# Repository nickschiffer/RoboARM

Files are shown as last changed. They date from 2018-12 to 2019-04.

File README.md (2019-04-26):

# RoboARM
## [Link to Hackster.io Post](https://www.hackster.io/154072/roboarm-texas-instruments-powered-3d-printed-robotic-arm-043960 "Hackster.io Post")
RoboARM utilizes a TM4C123GH6PM microcontroller to interpret inputs from an old analog joystick to control the servos that drive the arm; while at the same time making sure that the arm abides by the set movement bounds of the hardware. The microcontroller implements the added functionality of being able to record, store, and ultimately repeat routines that the operator performs.

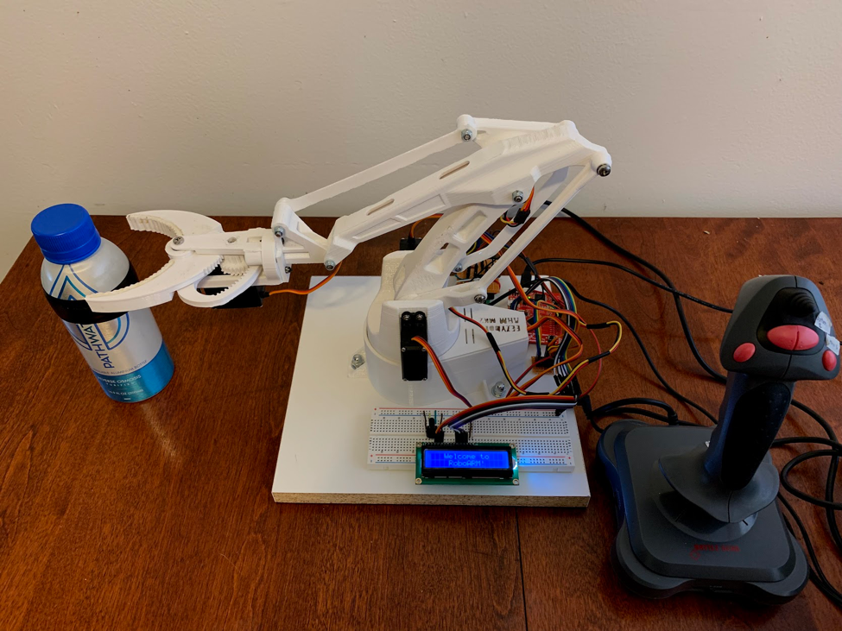
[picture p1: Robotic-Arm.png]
RoboARM


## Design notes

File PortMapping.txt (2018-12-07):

Pin Mappings:
    Joystick:
      (Port) : (Function) : (Signal)
       PB5   :    X1      : Analog
       PE4   :    Y1      : Analog
       PB1   :    B2      : Digital
       PB4   :    B3      : Digital
       PB3   :    B1      : Digital
       PB2   :    B4      : Digital
    Arm:
      (Port)   : (Function)   (Color)  : (Signal)
        PE0    : Up/Down      (Black)  :   PWM
        PE5    : Forward/Back (Green)  :   PWM
        PC5    : Claw	      (Yellow) :   PWM
        PC4    : Rotation     (Blue)   :   PWM

    Movement:
      Button 1: Close Claw
      Button 2: Up
      Button 3: Down
      Button 4: Open Claw

      x-axis: Rotation
      y-axis: Foward/Back

    Deadzone:
      x-avg = 1900 +/- 600
      y-avg = 1832 +/- 500

 The circuit for LCD:
 * LCD RS pin to digital pin 28 (PE2)
 * LCD Enable pin to digital pin 27  (PE1)
 * LCD D4 pin to digital pin 23 (PD0)
 * LCD D5 pin to digital pin 24 (PD1)
 * LCD D6 pin to digital pin 25 (PD2)
 * LCD D7 pin to digital pin 26 (PD3)
 * LCD R/W pin to ground
 * 10K resistor:
 * ends to +5V and ground
 * wiper to LCD VO pin (pin 3)

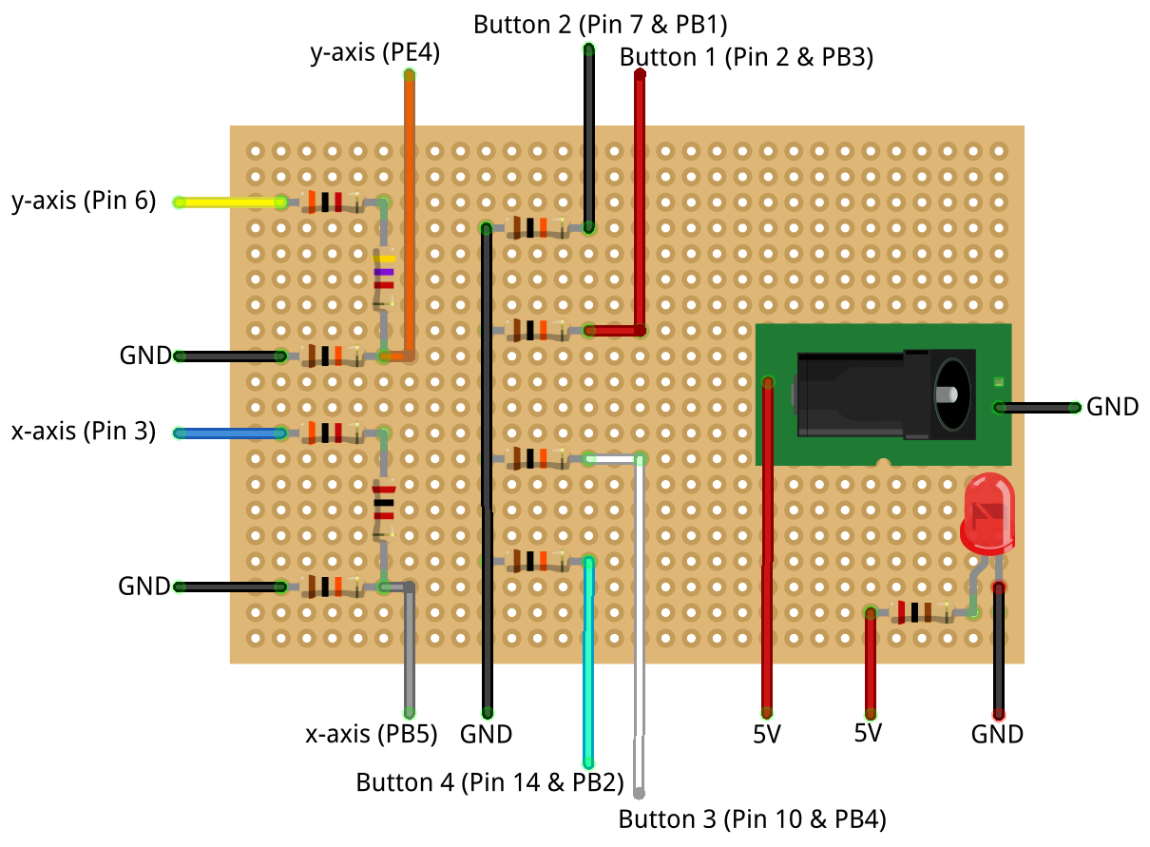
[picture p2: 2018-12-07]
Schematics/Circuit (VGA Connector).png

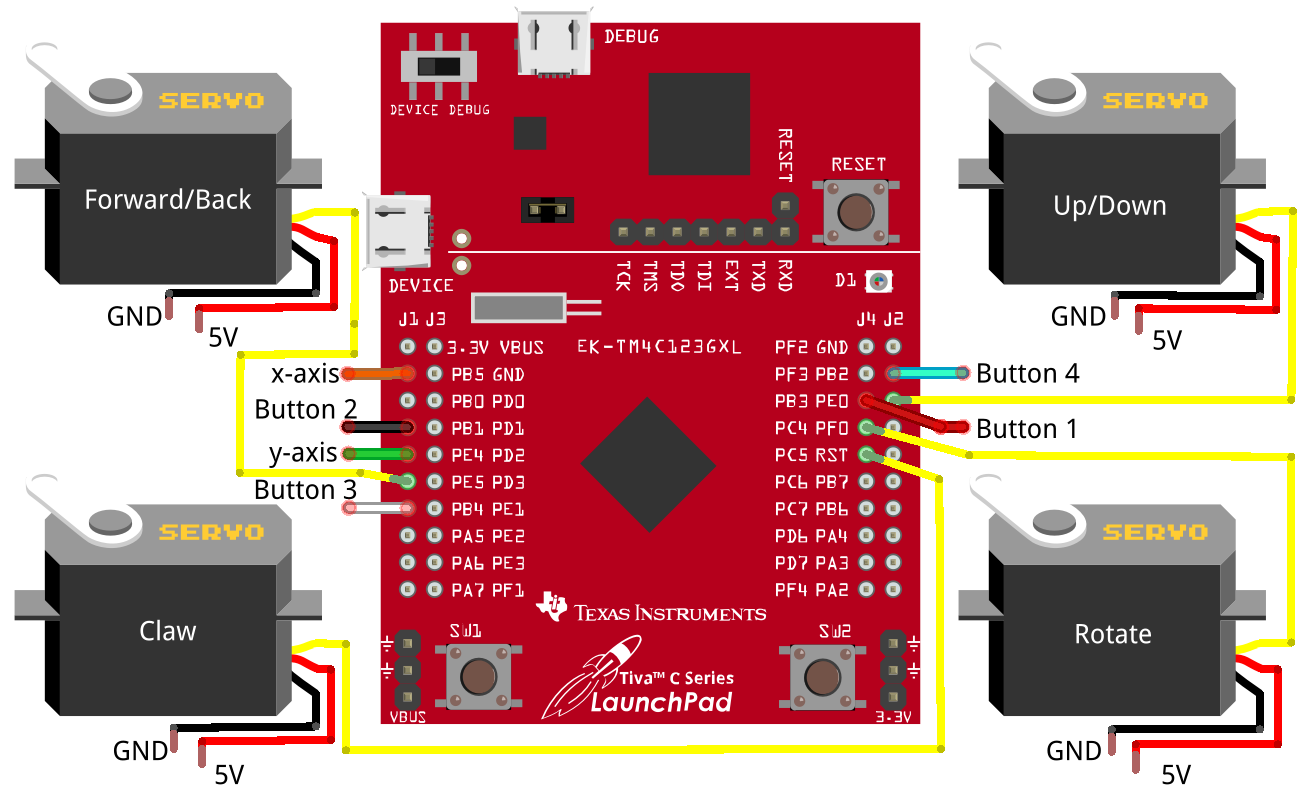
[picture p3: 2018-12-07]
Schematics/Tiva _ Servos.png

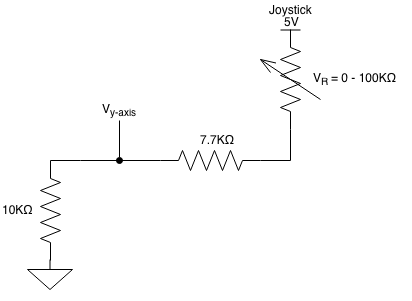
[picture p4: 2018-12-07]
Schematics/Voltage Divider (y-axis).png

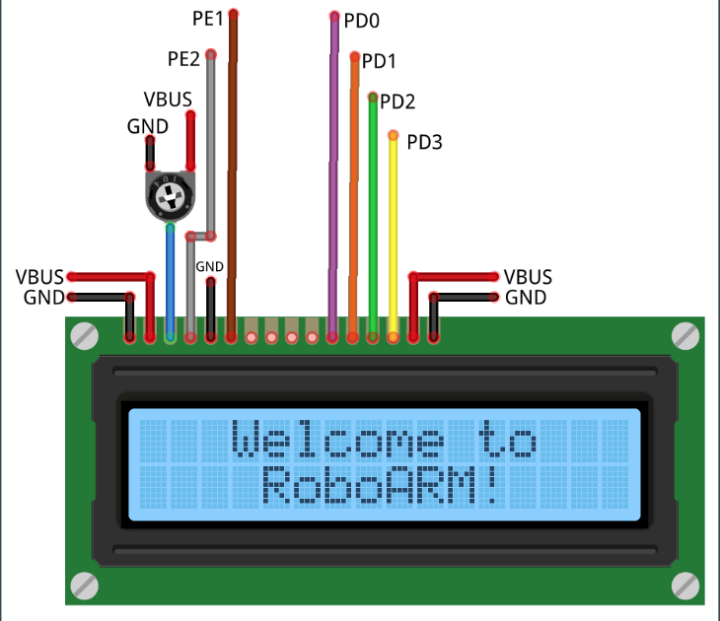
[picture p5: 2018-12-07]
Schematics/Screen Shot 2018-12-03 at 6.39.09 PM.png

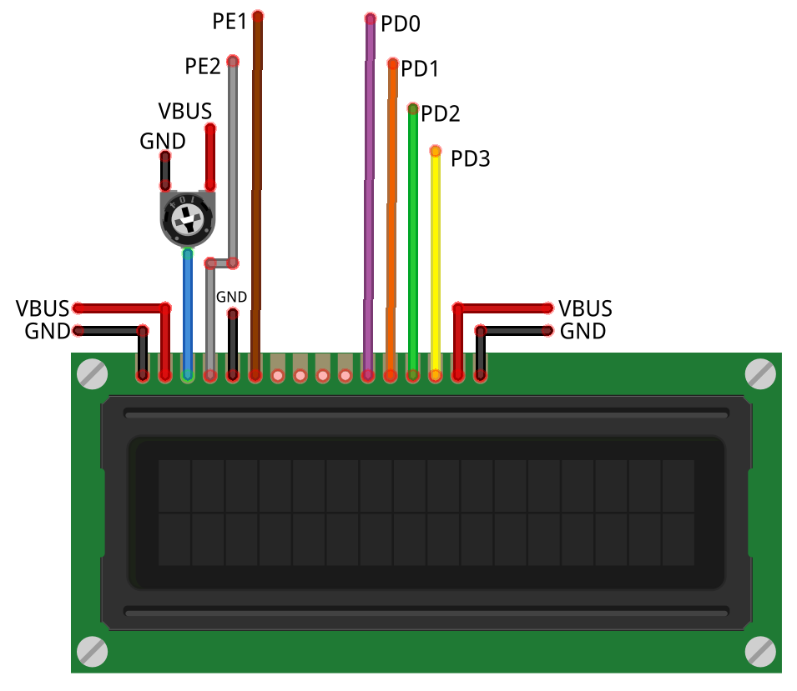
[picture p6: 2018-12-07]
Schematics/LCD Schematic.png

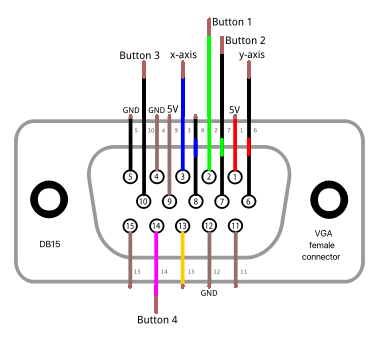
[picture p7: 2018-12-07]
Schematics/DB15 Connector Pins.png

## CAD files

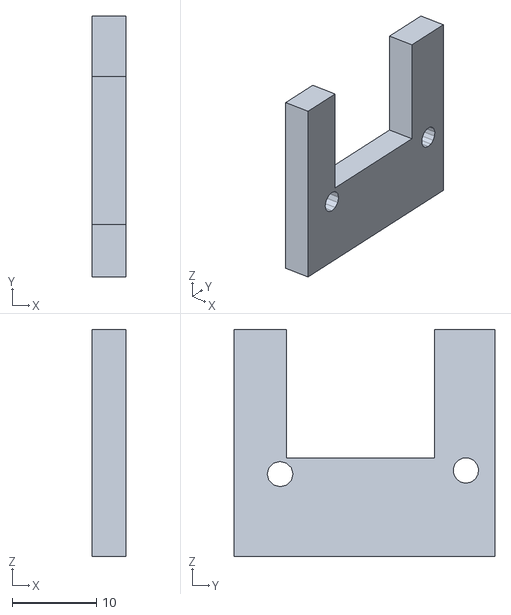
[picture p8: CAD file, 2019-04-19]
Claw-Adapter.stl
4.00 x 31.0 x 27.0

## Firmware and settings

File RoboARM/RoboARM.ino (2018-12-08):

/*
  RoboARM driver code:
  Pin Mappings:
    Joystick:
      (Port) : (Function) : (Signal)
       PB5   :    X1      : Analog
       PE4   :    Y1      : Analog
       PB1   :    B2      : Digital
       PB4   :    B3      : Digital
       PB3   :    B1      : Digital
       PB2   :    B4      : Digital
    Arm:
      (Port)   : (Function)   (Color)  : (Signal)
        PE0    : Up/Down      (Black)  :   PWM
        PE5    : Forward/Back (Green)  :   PWM
        PC5    : Claw         (Yellow) :   PWM
        PC4    : Rotation     (Blue)   :   PWM

    Movement:
      Button 1: Close Claw
      Button 2: Up
      Button 3: Down
      Button 4: Open Claw

      x-axis: Rotation
      y-axis: Foward/Back

    Deadzone:
      x-avg = 1900 +/- 600
      y-avg = 1832 +/- 500

 The circuit for LCD:
 * LCD RS pin to digital pin 28 (PE2)
 * LCD Enable pin to digital pin 27  (PE1)
 * LCD D4 pin to digital pin 23 (PD0)
 * LCD D5 pin to digital pin 24 (PD1)
 * LCD D6 pin to digital pin 25 (PD2)
 * LCD D7 pin to digital pin 26 (PD3)
 * LCD R/W pin to ground
 * 10K resistor:
 * ends to +5V and ground
 * wiper to LCD VO pin (pin 3)
 
 */
#include <stdio.h>
#include <Servo.h>
#include <LiquidCrystal.h> //https://github.com/energia/Energia/tree/master/libraries/LiquidCrystal


// #define DEBUG /* uncomment for Serial Debugging Output (causes severe lag with actual movements...Prints are expensive) */

//Servo Bounds
#define CLAW_OPEN_MAX 1
#define CLAW_CLOSED_MAX 150
#define CLAW_MOVEMENT_SPEED 5

#define ROTATE_LEFT_MAX 0
#define ROTATE_RIGHT_MAX 179
#define ROTATION_SPEED 2


#define UP_MAX 120
#define DOWN_MAX 74
#define UPDOWN_MOVEMENT_SPEED 2

#define DOWN_MAX_BACK 74
#define DOWN_MAX_FORWARD 0
int   downmax_height = 0;
int   downmax_width  = 0;
float downmax_slope  = 0;

#define FORWARD_MAX 179
#define BACK_MAX 89
#define FORWARD_BACK_SPEED 1
#define SENSITIVE_OFFSET 20

//Joystick Calibration
#define X_START 1900 //X Middle Point
#define Y_START 1832 //Y Middle Point
#define X_RANGE 600  //X Deadzone Threshold
#define Y_RANGE 500  //Y Deadzone Threshold

//recording
//#define RECORD_LENGTH (BUFSIZ + 500)
//#define RECORD_LENGTH (3*BUFSIZ + 500)
#define RECORD_LENGTH (6*BUFSIZ + 600)
int record_length =  RECORD_LENGTH;
//int record[RECORD_LENGTH][4];
//unsigned short int record[RECORD_LENGTH][4];
unsigned char record[RECORD_LENGTH][4];
int count = 0; //current recording position
bool recording = false;
bool playing   = false;
int cursor = 0;//current playback position

int progress_cursor = 0; // used for progress bar for recording and playback

//Inputs (used to store input values)
int x_val = 0;
int y_val = 0;

int B1_val = 0;
int B2_val = 0;
int B3_val = 0;
int B4_val = 0;


/* Analog */
int X1 = PB_5;
int Y1 = PE_4;
/* Digital */
int B2_pin = PB_1;
int B3_pin = PB_4;
int B1_pin = PB_3;
int B4_pin = PB_2; 

/* Servos */
int UpDown_pin      = PE_0;
int ForwardBack_pin = PE_5;
int Claw_pin        = PC_5;
int Rotate_pin      = PC_4;

/* Positional Variables */
int ClawPosition        = 0;
int RotationPosition    = 0;
int UpDownPosition      = 0;
int ForwardBackPosition = 0;

char str[200];

int current_down_max = 0;
bool adjusting_back  = false;

//Set up Servos
Servo UpDown;
Servo ForwardBack;
Servo Claw;
Servo Rotate;

// initialize the LCD library with the numbers of the interface pins (see mapping at top of file)
LiquidCrystal lcd(28, 27, 23, 24, 25, 26);

void moveClaw(char OpenOrClose){
  
  switch (OpenOrClose){
    case 'o' :
        if (ClawPosition > CLAW_OPEN_MAX + CLAW_MOVEMENT_SPEED){
            ClawPosition -= CLAW_MOVEMENT_SPEED;
            Claw.write(ClawPosition);
            #ifdef DEBUG
            sprintf(str, "Opening Claw. Claw Position: %d\n", ClawPosition);
            Serial.print(str);
            #endif
            
        }
        break;
    case 'c' :
        if (ClawPosition < CLAW_CLOSED_MAX - CLAW_MOVEMENT_SPEED){
            ClawPosition += CLAW_MOVEMENT_SPEED;
            Claw.write(ClawPosition);
            #ifdef DEBUG
            sprintf(str, "Closing Claw. Claw Position: %d\n", ClawPosition);
            Serial.print(str);
            #endif
        }
        break;
    case 'i':
        int default_val;
        default_val = (CLAW_CLOSED_MAX - CLAW_OPEN_MAX)/2;
        ClawPosition = default_val;
        Claw.write(default_val);
        #ifdef DEBUG
        sprintf(str, "Initializing CLaw. Claw Position: %d\n", ClawPosition);
        Serial.print(str);
        #endif
        break;
    default:
        break;
  }
}

void moveUpDown(char UpOrDown){
  
  switch (UpOrDown){
    case 'u' : //move up
        if (UpDownPosition + UPDOWN_MOVEMENT_SPEED < UP_MAX ){
            UpDownPosition += UPDOWN_MOVEMENT_SPEED;
            UpDown.write(UpDownPosition);
            #ifdef DEBUG
            sprintf(str, "Moving Up. UpDown Position: %d\n", UpDownPosition);
            Serial.print(str);
            #endif
            
        }
        break;
    case 'd' : //move down
            if (!adjusting_back){
              calcDownMax();
            }
        if (UpDownPosition - UPDOWN_MOVEMENT_SPEED > current_down_max){
            UpDownPosition -= UPDOWN_MOVEMENT_SPEED;
            UpDown.write(UpDownPosition);
            #ifdef DEBUG
            sprintf(str, "Moving Down. UpDown Position: %d, Current DownMax: %d\n", UpDownPosition, current_down_max);
            Serial.print(str);
            #endif
        }
        break;
    case 'i': //initialize
        int default_val;
        //default_val = abs(UP_MAX - DOWN_MAX)/2;
        default_val = 100;
        UpDown.write(default_val);
        UpDownPosition = default_val;
        #ifdef DEBUG
        sprintf(str, "Initializing UpDown. UpDown Position: %d\n", UpDownPosition);
        Serial.print(str);
        #endif
        break;
    default:
        break;
  }
}

void moveArmRotate(){
    //Rotate
    if (x_val > X_START + X_RANGE){ //Move if input value is outside of middle deadzone
      //Rotate Left
      if (ForwardBackPosition >= (FORWARD_MAX - SENSITIVE_OFFSET)){ //If close to the max front position, move more slowly
        if (RotationPosition - (ROTATION_SPEED - 1) >= ROTATE_LEFT_MAX){
          RotationPosition -= (ROTATION_SPEED - 1);
          Serial.println("Sensitive Left");
          Rotate.write(RotationPosition);
          #ifdef DEBUG
          sprintf(str, "Rotating Left. Rotation Position: %d\n", RotationPosition);
          Serial.print(str);
          #endif
        }
      }
      
      else if (RotationPosition - ROTATION_SPEED >= ROTATE_LEFT_MAX){ //check to see if movement will go out of bounds
        RotationPosition -= ROTATION_SPEED;
        Rotate.write(RotationPosition);
        #ifdef DEBUG
        sprintf(str, "Rotating Left. Rotation Position: %d\n", RotationPosition);
        Serial.print(str);
        #endif
      }
    }
    if (x_val < X_START - X_RANGE){ //Move if input value is outside of middle deadzone
      //Rotate Right
      if (ForwardBackPosition >= (FORWARD_MAX - SENSITIVE_OFFSET)){ //If close to the max front position, move more slowly
        if (RotationPosition + (ROTATION_SPEED - 1) <= ROTATE_RIGHT_MAX){ //check to see if movement will go out of bounds
          RotationPosition += (ROTATION_SPEED - 1);
          Serial.println("Sensitive Right");
          Rotate.write(RotationPosition);
          #ifdef DEBUG
          sprintf(str, "Rotating Right. Rotation Position: %d\n", RotationPosition);
          Serial.print(str);
          #endif
        }
      }
      else if (RotationPosition + ROTATION_SPEED <= ROTATE_RIGHT_MAX){ //check to see if movement will go out of bounds
        RotationPosition += ROTATION_SPEED;
        Rotate.write(RotationPosition);
        #ifdef DEBUG
        sprintf(str, "Rotating Right. Rotation Position: %d\n", RotationPosition);
        Serial.print(str);
        #endif
      }
    }
}

void moveArmForwardBack(){
  //Forward or Back
    if (y_val > Y_START + Y_RANGE){ //Move if input value is outside of middle deadzone
      //Move Forward
      if (ForwardBackPosition + FORWARD_BACK_SPEED <= FORWARD_MAX){ //check to see if movement will go out of bounds
        ForwardBackPosition += FORWARD_BACK_SPEED;
        ForwardBack.write(ForwardBackPosition);
        #ifdef DEBUG
        sprintf(str, "Moving Forward. ForwardBack Position: %d\n", ForwardBackPosition);
        Serial.print(str);
        #endif
      }
    }
    if (y_val < Y_START - Y_RANGE){ //Move if input value is outside of middle deadzone
      //Move Back
      if (ForwardBackPosition - FORWARD_BACK_SPEED >= BACK_MAX){ //check to see if movement will go out of bounds
        
        ForwardBackPosition -= FORWARD_BACK_SPEED;
        ForwardBack.write(ForwardBackPosition);
        #ifdef DEBUG
        sprintf(str, "Moving Back. ForwardBack Position: %d\n", ForwardBackPosition);
        Serial.print(str);
        #endif
        calcDownMax();
        /* If the arm is moved back and is lower than the lowest allowed position for that ForwardBackPosition, we need to move the arm up.*/
        if (UpDownPosition < current_down_max){
          #ifdef DEBUG
          Serial.println("adjusting\n");
          #endif
          adjusting_back = true;
          moveUpDown('u');
          adjusting_back = false;
        }
      }
    }
  
}

/* Used to calculate the lowest point the arm can go depending on its current ForwardBackPosition (Think Triangle, y=mx+b) */
void calcDownMax(){
  current_down_max = (int)((float)downmax_slope*(float)abs(FORWARD_MAX - ForwardBackPosition));
  #ifdef DEBUG
  sprintf(str, "height: %d, width: %d, slope: %g, currentdownmax: %d\n", downmax_height, downmax_width, downmax_slope, current_down_max);
  Serial.print(str);
  #endif
  
}

/* Prints the Welcome Message when the bot is powered on or reset */
void printWelcome(){
  // set up the LCD's number of columns and rows: 
  lcd.begin(16, 2);
  // Print a message to the LCD.
  lcd.print("   Welcome to");
  delay(2000);
  lcd.setCursor(0, 1);
  lcd.print("    RoboARM!");
  delay(2000);
  lcd.setCursor(0,0);
  lcd.print("                ");
  lcd.setCursor(0,1);
  lcd.print("   Welcome to");
  delay(750);
  lcd.clear();
  lcd.setCursor(0,0);
  lcd.print("Initializing");
  int lcd_cursor = 12;
  for (int i = 0; i < 3; i++){
    for (int j = 0; j < 3; j++){
      lcd.setCursor(lcd_cursor++, 0);
      lcd.print(".");
      delay(600);
    }
    lcd.setCursor(12,0);
    lcd.print("   ");
    lcd_cursor = 12;
    delay(500);
  }
  byte block[8] = {
    0b00000,
    0b11111,
    0b11111,
    0b11111,
    0b11111,
    0b11111,
    0b11111,
    0b00000  
  };
  lcd.createChar(0, block);
  byte play[8] = {
    0b01000,
    0b01100,
    0b01110,
    0b01111,
    0b01110,
    0b01100,
    0b01000,
    0b00000
  };
  lcd.createChar(1, play);
  byte rec[8] = {
    0b00000,
    0b01110,
    0b11111,
    0b11111,
    0b11111,
    0b01110,
    0b00000,
    0b00000
  };
  lcd.createChar(2, rec);
}

void setup() {
  
  
  
  Serial.begin(9600);
  Serial.print("Starting\n");
  printWelcome();
  lcd.setCursor(0,0);
  lcd.print("Mode: Manual");
  //Setup digital inputs
  pinMode(B1_pin,INPUT);
  pinMode(B2_pin,INPUT);
  pinMode(B3_pin,INPUT);
  pinMode(B4_pin,INPUT);
  pinMode(PUSH1, INPUT_PULLUP);
  pinMode(PUSH2, INPUT_PULLUP);
  
  //recording and playback Interrupt Initialization
  attachInterrupt(digitalPinToInterrupt(PUSH1), toggleRecord, FALLING);
  attachInterrupt(digitalPinToInterrupt(PUSH2), togglePlayback, FALLING);

  //Attach Servos
  UpDown.attach(UpDown_pin);
  ForwardBack.attach(ForwardBack_pin);
  Claw.attach(Claw_pin);
  Rotate.attach(Rotate_pin);

  //Set Servos to Default
  moveClaw('i');
  moveUpDown('i');

  //intitialize Rotation to middle point of bounds
  RotationPosition = abs(ROTATE_LEFT_MAX - ROTATE_RIGHT_MAX)/2;
  Rotate.write(RotationPosition);
  sprintf(str, "Initializing Rotate. RotationPosition: %d\n", RotationPosition);
  Serial.print(str);

  //Initialize ForwardBack
  //ForwardBackPosition = abs(FORWARD_MAX - BACK_MAX)/2;
  ForwardBackPosition = 100;
  ForwardBack.write(ForwardBackPosition);
  sprintf(str, "Initializing ForwardBack. ForwardBackPosition: %d\n", ForwardBackPosition);
  Serial.print(str);


  downmax_height = abs(DOWN_MAX_BACK - DOWN_MAX_FORWARD);
  downmax_width  = abs(FORWARD_MAX - BACK_MAX);
  downmax_slope  = (float)downmax_height/(float)downmax_width;
  calcDownMax();
  
}


/* Recording is toggled via hardware interrupt if record button is pressed */
void toggleRecord(){
  
  if (recording){
    #ifdef DEBUG
    sprintf(str, "Stopping Recording... Length: %d\n", count);
    Serial.print(str);
    #endif
    lcd.setCursor(6,0);
    lcd.print("Manual    ");
    recording = false;
    lcd.setCursor(0,1);
    lcd.print("                ");
    progress_cursor = 0;
  }
  else{
    #ifdef DEBUG
    Serial.println("Starting Recording...");
    #endif
    lcd.setCursor(6,0);
    lcd.print("Record ");
    lcd.write((byte) 2);
    recording = true;
    count = 0;
  }
  
  
  
}

/* Playback is toggled via hardware interrupt if playback button is pressed */
void togglePlayback(){
  
  if (recording) //If recording, the recording needs to be concluded before playback can occur
      recording = false;
      lcd.setCursor(0,1);
      lcd.print("                ");
      progress_cursor = 0;
  if (!playing){
    if (count != 0){
      #ifdef DEBUG
      Serial.println("Playing");
      #endif
      lcd.setCursor(6,0);
      lcd.print("Playback ");
      lcd.write((byte) 1);
      playing = true;
      cursor = 0;
      }
      else {
        #ifdef DEBUG
        Serial.println("No recording to play back");
        #endif
      }
    }
    else{
      playing = false;
      #ifdef DEBUG
      Serial.println("Playback Finished");
      #endif
      lcd.setCursor(0,1);
      lcd.print("    Finished");
      delay(1000);
      lcd.setCursor(0,1);
      lcd.print("                ");
      lcd.setCursor(6,0);
      lcd.print("        ");
      lcd.setCursor(6,0);
      
      lcd.print("Manual    ");
      cursor = 0;
    }
  
}


void loop() {
   
  // read the values from the sensor if playback is not active:
  if (!playing){
    x_val = analogRead(X1);
    y_val = analogRead(Y1);   

    B1_val = digitalRead(B1_pin);
    B2_val = digitalRead(B2_pin);  
    B3_val = digitalRead(B3_pin);  
    B4_val = digitalRead(B4_pin);

    /* Claw */
   if (B1_val == HIGH){
      moveClaw('c'); //close claw
   }
   else if (B4_val == HIGH){
      moveClaw('o'); //open claw
   }

    if (B2_val == HIGH){
      moveUpDown('u'); //move up
    }
    else if (B3_val == HIGH){
      moveUpDown('d'); //move down
    }

    moveArmRotate();
    moveArmForwardBack();
    
    /* If recording and still have room to record, store current positions into record array */
    if (recording){
        if (count != record_length - 1){
          #ifdef DEBUG
          Serial.print("count:");
          Serial.println(count);
          #endif 
          record[count][0] = ClawPosition;
          record[count][1] = RotationPosition;
          record[count][2] = UpDownPosition;
          record[count][3] = ForwardBackPosition;
          count++;

          /* Map recording position to [0 : 16] and print status bar accordingly */
          int progress_block = map(count, 0, record_length, 0, 17);
          if (progress_block > progress_cursor){
            lcd.setCursor(progress_cursor, 1);
            lcd.write((byte) 0);
            progress_cursor = progress_block; 
          }
      }
      else {
        toggleRecord();
      }
    }
  }
  else {
    /* If Playing Back, write recorded position values directly to Servos */
    Claw.write(record[cursor][0]);
    Rotate.write(record[cursor][1]);
    UpDown.write(record[cursor][2]);
    ForwardBack.write(record[cursor][3]);

    /* Map current playback position out of record length into 0 : 16. Then write to status bar */
    int progress_block = map(cursor, 0, count, 0, 17);
    if (progress_block > progress_cursor){
      lcd.setCursor(progress_cursor, 1);
      lcd.write((byte) 0);
      progress_cursor = progress_block; 
    }
    if (cursor < count - 1){
      cursor++;
    }
    else {
      togglePlayback(); //stop playback once it has reached the end
    }
  }
   delay(20);
}

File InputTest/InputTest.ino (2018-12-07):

/*
  Analog Input
 Used to Calibration/Statitics for analog inputs from joystick.
 
 */
#include <stdio.h>

 
int x_val = 0;
int y_val = 0;

int B1_val = 0;
int B2_val = 0;
int B3_val = 0;
int B4_val = 0;

//For delta tuning
bool firstpass = true;
int firstpass_x = 0;
int firstpass_y = 0;
int x_delta_high_mid = 0;
int x_delta_low_mid = 0;
int y_delta_high_mid = 0;
int y_delta_low_mid = 0;


/* Analog */
int X1 = PB_5;
int Y1 = PD_2;
/* Digital */
int B2_pin = PB_1;
int B3_pin = PB_4;
int B1_pin = PB_3;
int B4_pin = PB_2;

 //Average
 long long sum_x = 0;
 long long sum_y = 0;
 long count = 0;
 int avg_x, avg_y;

char str[2048];

void setup() {
  pinMode(B1_pin,INPUT);
  pinMode(B2_pin,INPUT);
  pinMode(B3_pin,INPUT);
  pinMode(B4_pin,INPUT);  

  Serial.begin(9600);
  
  
}

void loop() {

  // get middle values for x and y (for tuning)
  if (firstpass){
    firstpass_x = analogRead(X1);
    firstpass_y = analogRead(Y1);
    firstpass = false;
  }

  
  
  
  // read the value from the sensor:
  x_val = analogRead(X1);
  y_val = analogRead(Y1);   
  // turn the ledPin on
  B1_val = digitalRead(B1_pin);
  B2_val = digitalRead(B2_pin);  
  B3_val = digitalRead(B3_pin);  
  B4_val = digitalRead(B4_pin); 

  //Average Calculation
  sum_x += x_val;
  sum_y += y_val;
  count++;
  avg_x = sum_x / count;
  avg_y = sum_y / count;
  



  // Calculate Deltas (for tuning)
  x_delta_high_mid = x_val - firstpass_x;
  x_delta_low_mid  = firstpass_x - x_val;

  y_delta_high_mid = y_val - firstpass_y;
  y_delta_low_mid  = firstpass_y - y_val;
  

  //sprintf(str, "X_val: %d, Y_val: %d, B1: %d, B2: %d, B3: %d, B4: %d\n", x_val, y_val, B1_val, B2_val, B3_val, B4_val);
  sprintf(str, "X_val: %5d, Y_val: %5d, X_avg: %5d, Y_avg: %5d, x_delta_high_mid: %5d, x_delta_low_mid: %5d, y_delta_high_mid: %5d, y_delta_low_mid: %5d\n", x_val, y_val, avg_x, avg_y, x_delta_high_mid, x_delta_low_mid, y_delta_high_mid, y_delta_low_mid);

  Serial.print(str); 
    
  delay(20);
}

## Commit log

2019-03-08 Uploaded picture of the arm
2019-04-19 Uploaded stl file of the claw adapter
    [Claw-Adapter.stl]
